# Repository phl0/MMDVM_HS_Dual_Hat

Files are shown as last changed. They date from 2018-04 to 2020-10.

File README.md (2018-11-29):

# MMDVM_HS_Dual_Hat
Duplex variant of MMDVM_HS_Hat
DB9MAT DF2ET DO7EN

This PCB uses the [MMDVM_HS](https://github.com/juribeparada/MMDVM_HS) by Andy CA6JAU. It has two ADF7021 onboard and allows for duplex operation with two time slots on DMR.

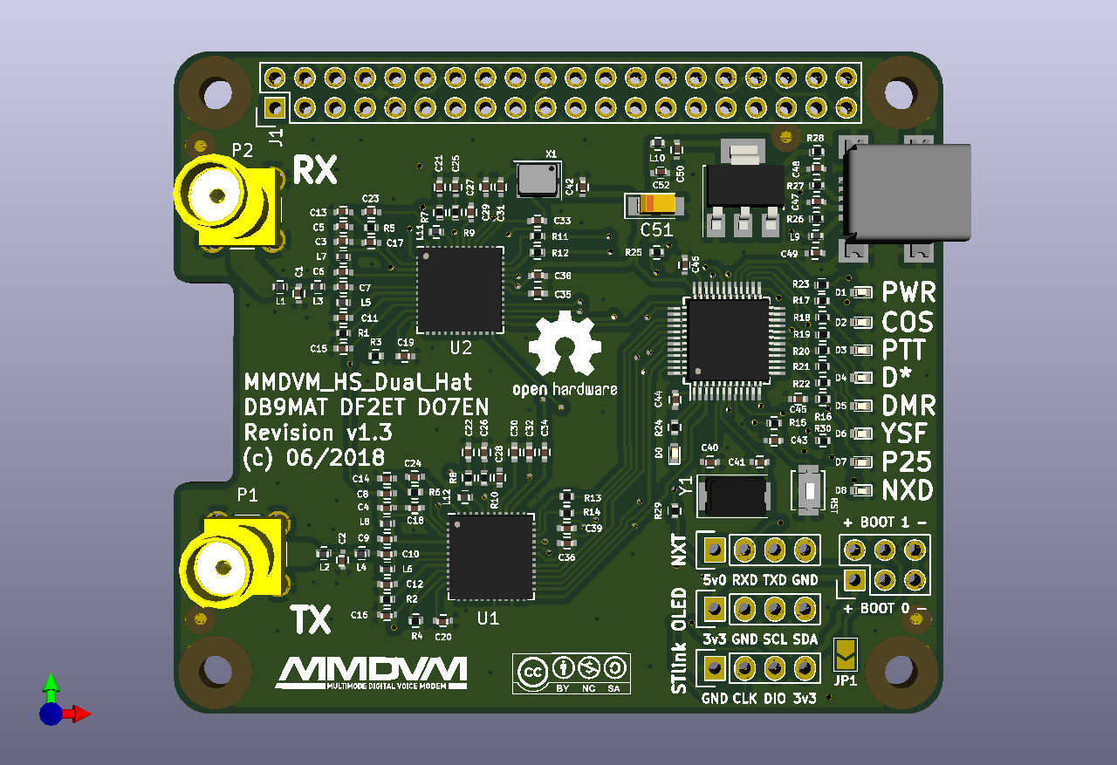
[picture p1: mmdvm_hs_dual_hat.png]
MMDVM_HS_Dual_Hat


## Revisions

### Revision 1.0

Initial release.

### Revision 1.1

LEDs D4 and D5 interchanged to align with scan order. Solder jumper JP1 was added. It can be closed if the board is used on Raspberry Pi only. It ties BOOT1 to GND. BOOT0 is controlled via GPIO. The 2x3 pin header can be unpopulated in this case to save space. We placed two coils on U1 and U2 for experiments with extended VCO. These are L11 and L12 and they are optional and do not need to be inserted for UHF use. Testpoints TP1 and TP2 on backside allows the demodulator output SNR to be measured with #define TEST_DAC compiled firmware.

**This version is not recommended for (re-)production!**

### Revision 1.2

An accidentially deleted 3v3 wire has been added back to the PCB layout. BOM, Mouser cart and stencil stay the same as for rev1.1.

### Revision 1.3

STlink header has been refactored to have the same pinout as the [MMDVM_HS_Hat](https://github.com/mathisschmieder/MMDVM_HS_Hat) boards. OLED and STlink header have been exchanged. JP1 has been slightly moved. C44, C45 and C46 have been relocated nearer to the STM32F1 CPU. A table was added to the bottom silkscreen to show which TCXO is installed. This is important to the firmware. BOM and Mouser cart are still the same. The stencil has slightly changed. If you manually solder C44-C46 you can still use the old one.

## BOM

Mouser cart for rev1.0 is [here](https://www.mouser.com/ProjectManager/ProjectDetail.aspx?AccessID=561bb01347).

[This](https://www.mouser.com/ProjectManager/ProjectDetail.aspx?AccessID=24ea9d644e) is the Mouser cart for rev1.1. L11 and L12 are optional.

## Firmware installation

The device can be used on top on a RPi attached via the GPIO port or standalone and connected via USB. Both variants require different handling of compiling and uploading the firmware. The USB connection requires firmware with bootloader support whereas the GPIO version does not. 

For USB connection a bootloader has to be installed initally. This requires STlink connection. After that is done the MMDVM_HS firmware upgrade can be done via the USB connection. The STlink connection can be used as fallback if wrongly configured firmware was installed for example.

### Install the firmware with bootloader support for USB connection

If you want to use the device via USB port you have to install a bootloader and build the firmware with bootloader support. As the raw device cannot be used with USB you have to use a USB-serial adapter or STlink device. Using STlink this can be done as follows:

```
user@host:/opt/MMDVM_HS$ make stlink-bl 
././STM32F10X_Lib/utils/linux64/st-flash write ./STM32F10X_Lib/utils/bootloader/generic_boot20_pc13.bin 0x8000000
2018-03-02T10:01:04 INFO src/usb.c: -- exit_dfu_mode
2018-03-02T10:01:04 INFO src/common.c: Loading device parameters....
2018-03-02T10:01:04 INFO src/common.c: Device connected is: F1 Medium-density device, id 0x20036410
2018-03-02T10:01:04 INFO src/common.c: SRAM size: 0x5000 bytes (20 KiB), Flash: 0x10000 bytes (64 KiB) in pages of 1024 bytes
2018-03-02T10:01:04 INFO src/common.c: Attempting to write 7160 (0x1bf8) bytes to stm32 address: 134217728 (0x8000000)
Flash page at addr: 0x08001800 erased
2018-03-02T10:01:04 INFO src/common.c: Finished erasing 7 pages of 1024 (0x400) bytes
2018-03-02T10:01:04 INFO src/common.c: Starting Flash write for VL/F0/F3 core id
2018-03-02T10:01:04 INFO src/common.c: Successfully loaded flash loader in sram
  6/6 pages written
2018-03-02T10:01:05 INFO src/common.c: Starting verification of write complete
2018-03-02T10:01:05 INFO src/common.c: Flash written and verified! jolly good!
././STM32F10X_Lib/utils/linux64/st-flash write bin/mmdvm_f1bl.bin 0x8002000
2018-03-02T10:01:05 INFO src/common.c: Loading device parameters....
2018-03-02T10:01:05 INFO src/common.c: Device connected is: F1 Medium-density device, id 0x20036410
2018-03-02T10:01:05 INFO src/common.c: SRAM size: 0x5000 bytes (20 KiB), Flash: 0x10000 bytes (64 KiB) in pages of 1024 bytes
2018-03-02T10:01:05 INFO src/common.c: Attempting to write 55016 (0xd6e8) bytes to stm32 address: 134225920 (0x8002000)
Flash page at addr: 0x0800f400 erased
2018-03-02T10:01:07 INFO src/common.c: Finished erasing 54 pages of 1024 (0x400) bytes
2018-03-02T10:01:07 INFO src/common.c: Starting Flash write for VL/F0/F3 core id
2018-03-02T10:01:07 INFO src/common.c: Successfully loaded flash loader in sram
 53/53 pages written
2018-03-02T10:01:12 INFO src/common.c: Starting verification of write complete
2018-03-02T10:01:13 INFO src/common.c: Flash written and verified! jolly good!
```

The device should now be usable as /dev/ttyACMx. 

If you want to update the MMDVM_HS firmware itself later on via USB you can use the dfu upload method. The settings in Config.h are:

    #define MMDVM_HS_DUAL_HAT_REV10
    #define ENABLE_ADF7021
    #define DUPLEX

    #define ADF7021_14_7456

or
    #define ADF7021_12_2880

for boards with 12.288MHz TCXO.

    #define STM32_USB_HOST
    #define ENABLE_SCAN_MODE

Optionally:

    #define SEND_RSSI_DATA
    #define SERIAL_REPEATER

Compile the firmware with "make bl" and then:

```
user@host:/opt/MMDVM_HS$ sudo make dfu devser=/dev/ttyACM3
././STM32F10X_Lib/utils/linux64/upload-reset /dev/ttyACM3 750
././STM32F10X_Lib/utils/linux64/dfu-util -D bin/mmdvm_f1bl.bin -d 1eaf:0003 -a 2 -R -R
dfu-util 0.7

Copyright 2005-2008 Weston Schmidt, Harald Welte and OpenMoko Inc.
Copyright 2010-2012 Tormod Volden and Stefan Schmidt
This program is Free Software and has ABSOLUTELY NO WARRANTY
Please report bugs to dfu-util@lists.gnumonks.org

Filter on vendor = 0x1eaf product = 0x0003
Opening DFU capable USB device... ID 1eaf:0003
Run-time device DFU version 0110
Found DFU: [1eaf:0003] devnum=0, cfg=1, intf=0, alt=2, name="STM32duino bootloader v1.0  Upload to Flash 0x8002000"
Claiming USB DFU Interface...
Setting Alternate Setting #2 ...
Determining device status: state = dfuIDLE, status = 0
dfuIDLE, continuing
DFU mode device DFU version 0110
Device returned transfer size 1024
No valid DFU suffix signature
Warning: File has no DFU suffix
bytes_per_hash=1100
Copying data from PC to DFU device
Starting download: [##################################################] finished!
state(8) = dfuMANIFEST-WAIT-RESET, status(0) = No error condition is present
Done!
Resetting USB to switch back to runtime mode
```

### Compile and upload manually for GPIO connection

For specific details about the firmware installation, check [these](https://github.com/juribeparada/MMDVM_HS#build-de-firmware-and-upload-to-zumspot-rpi) instructions. The process is similar to the installation on the ZumSpot Pi. You can make use of the preconfigured scripts in MMDVM_HS. Editing Config.h by hand requires these settings:

Enable the following settings in Config.h: 

    #define MMDVM_HS_DUAL_HAT_REV10
    #define ENABLE_ADF7021
    #define DUPLEX
    #define ADF7021_14_7456
    #define STM32_USART1_HOST
    #define ENABLE_SCAN_MODE

Optionally:

    #define SEND_RSSI_DATA
    #define SERIAL_REPEATER

And for 12.288MHz TCXO equipped boards

    #define ADF7021_12_2880

instead of the 14_7456 option.

Build the firmware:

    make

Make sure the two BOOT jumpers are set as follows:

    BOOT0: completey removed
    BOOT1: set to BOOT 1 -

And finally upload the firmware to the MMDVM_HS_Dual_Hat:

    sudo make mmdvm_hs_dual_hat

### Update within Pi-Star

[PiStar](http://www.pistar.uk/) contains a binary that allow for flashing precompiled binary firmware to the MMDVM_HS_Dual_Hat. To update the firmware within PiStar execute the following commands:

    $ rpi-rw
    $ pistar-mmdvmhshatflash hs_dual_hat

If you have a board equipped with 12.288MHz TCXO you have to flash the according firmware type using:

    $ pistar-mmdvmhshatflash hs_dual_hat-12mhz

## License
This project is released under the Creative Commons Attribution-NonCommercial-ShareAlike 3.0 (CC-BY-NC-SA 3.0, https://creativecommons.org/licenses/by-nc-sa/3.0/) license. You may edit and share it as you like, as long as credit is given and the license is not changed. You can build as many boards for you and your friends as you like and you can even sell it to them to cover your costs, **however it is strictly forbidden to turn this into a commercial product! You are not allowed to build and sell these boards for profit!**

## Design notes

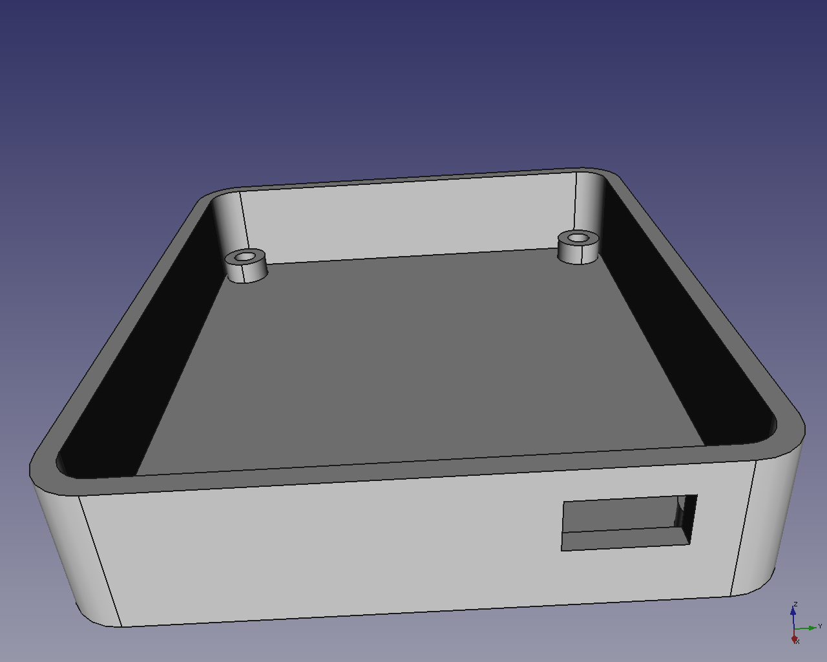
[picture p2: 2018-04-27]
case/MMDVM_HS_Dual_Hat_base.png

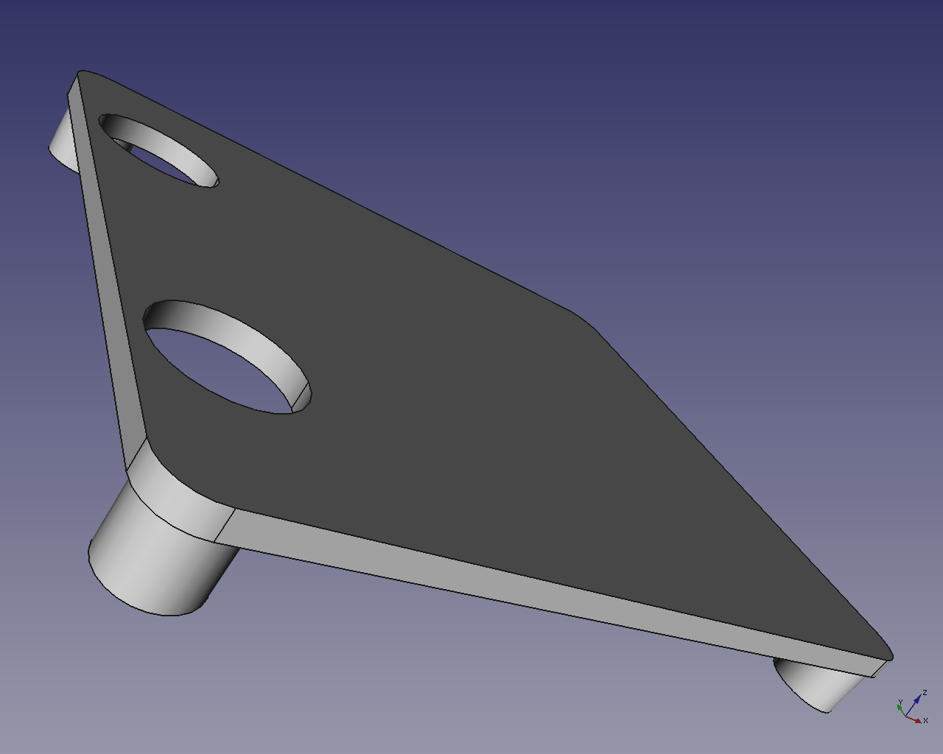
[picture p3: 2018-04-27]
case/MMDVM_HS_Dual_Hat_top.png

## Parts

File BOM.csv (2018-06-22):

Refs | Value | Footprint | Quantity | MFR | MPN | SPR | SPN
SW1 | NO | Buttons_Switches_SMD:SW_SPST_B3U-1000P | 1 | Omron Electronics | B3U-1000P | Mouser | 653-B3U-1000P
C43;C44;C45;C46;C50;C36;C20;C14;C30;C35;C19;C13;C29 | 100n | Capacitors_SMD:C_0402 | 13 | Vishay / Vitramon | VJ0402V104ZXJCW1BC | Mouser | 77-VJ0402V104ZXJCBC
C49;C39;C16;C18;C4;C32;C42;C38;C15;C17;C3;C31 | 10n | Capacitors_SMD:C_0402 | 12 | Vishay / Vitramon | VJ0402Y103KXJCW1BC | Mouser | 77-VJ0402Y103KXJCBC
C9;C6 | 10p | Capacitors_SMD:C_0402 | 2 | Murata Electronics | GRM1555C1E100GA01D | Mouser | 81-GRM1555C1E100GA1D
C52 | 10u | Capacitors_SMD:C_0402 | 1 | Murata Electronics | GRM155C80J106ME11J | Mouser | 81-GRM155C80J106ME1J
C26;C25 | 15n | Capacitors_SMD:C_0402 | 2 | Murata Electronics | GRM155R71C153KA01J | Mouser | 81-GRM155R71C153KA1J
C28;C27 | 1n | Capacitors_SMD:C_0402 | 2 | Murata Electronics | GRM155R60J102KA01D | Mouser | 81-GRM155R60J102KA1D
C40;C41 | 20p | Capacitors_SMD:C_0402 | 2 | Murata Electronics | GJM1555C1H200FB01D | Mouser | 81-GJM1555C1H200FB1D
C8;C5 | 220p | Capacitors_SMD:C_0402 | 2 | Murata Electronics | GRM1555C1H221JA01D | Mouser | 81-GRM1555C1H221JA01
C24;C23 | 22n | Capacitors_SMD:C_0402 | 2 | Murata Electronics | GCM155R71E223KA55D | Mouser | 81-GCM155R71E223KA5D
C34;C33 | 22p | Capacitors_SMD:C_0402 | 2 | AVX | 04025A220GAT2A | Mouser | 581-04025A220G
C22;C21 | 470p | Capacitors_SMD:C_0402 | 2 | Murata Electronics | GCM1555C1H471JA16J | Mouser | 81-GCM1555C1H471JA6J
C48;C47 | 47p | Capacitors_SMD:C_0402 | 2 | Murata Electronics | GRM1555C1H470FA01D | Mouser | 81-GRM1555C1H470FA1D
C10;C7 | 4p7 | Capacitors_SMD:C_0402 | 2 | Murata Electronics | GRM1555C1H4R7CA01D | Mouser | 81-GRM1555C1H4R7CA1D
C12;C2;C11;C1 | 6p8 | Capacitors_SMD:C_0402 | 4 | Murata Electronics | GJM1555C1H6R8BB01D | Mouser | 81-GJM1555C1H6R8BB1D
C51 | 10u/10V | Capacitors_Tantalum_SMD:CP_Tantalum_Case-A_EIA-3216-18_Reflow | 1 | AVX | TPSA106K010T0900 | Mouser | 581-TPSA106K010T0900
P2;P1 | SMA | Connectors:SMA_THT_Jack_Straight | 2 | TE Connectivity | 5-1814832-1 | Mouser | 571-5-1814832-1
W1;W2 | TEST_1P | Connectors_TestPoints:Test_Point_Pad_1.0x1.0mm | 2
X1 | TCXO | Crystals:Crystal_SMD_3225-4pin_3.2x2.5mm | 1 | ECS | ECS-TXO-3225-147.4-TR | Mouser | 520-TXO-3225-14.74T
Y1 | 8MHz | Crystals:Crystal_SMD_Abracon_ABM3-2pin_5.0x3.2mm | 1 | ABRACON | ABM3-8.000MHz-D2Y-T | Mouser | 815-ABM3-8-D2Y-T
U1;U2 | ADF7021 | Housings_DFN_QFN:QFN-48-1EP_7x7mm_Pitch0.5mm | 2 | Analog Devices | ADF7021BCPZ | Mouser | 584-ADF7021BCPZ
U3 | STM32F103C8T6 | Housings_QFP:LQFP-48_7x7mm_Pitch0.5mm | 1 | STMicroelectronics | STM32F103C8T6 | Mouser | 511-STM32F103C8T6
L9 | 100MHz | Inductors_SMD:L_0402 | 1 | Wurth Electronics | 74279277 | Mouser | 710-74279277
L10 | 10u | Inductors_SMD:L_0402 | 1 | Wurth Electronics | 74279277 | Mouser | 710-74279277
L8;L7 | 13n | Inductors_SMD:L_0402 | 2 | Murata Electronics | LQW15AN13NG80D | Mouser | 81-LQW15AN13NG80D
L12;L11 | 18n | Inductors_SMD:L_0402 | 2 | TE Connectivity / Sigma Inductors | 36501E18NJTDG | Mouser | 279-36501E18NJTDG
L4;L3 | 20n | Inductors_SMD:L_0402 | 2 | TE Connectivity / Sigma Inductors | 36501E20NJTDG | Mouser | 279-36501E20NJTDG
L2;L1 | 22n | Inductors_SMD:L_0402 | 2 | Murata Electronics | LQW15CA22NJ00D | Mouser | 81-LQW15CA22NJ00D
L6;L5 | 27n | Inductors_SMD:L_0402 | 2 | Murata Electronics | LQW15AN27NG80D | Mouser | 81-LQW15AN27NG80D
JP1 | SolderJumper_2_Open | Jumper:SolderJumper-2_P1.3mm_Open_TrianglePad1.0x1.5mm | 1
D6 | amber | LEDs:LED_0402 | 1 | Kingbright | APHHS1005SECK | Mouser | 604-APHHS1005SECK
D8 | blue | LEDs:LED_0402 | 1 | Kingbright | APHHS1005QBC/D | Mouser | 604-APHHS1005QBCD
D1;D4 | green | LEDs:LED_0402 | 2 | Kingbright | APHHS1005CGCK | Mouser | 604-APHHS1005CGCK
D3;D7;D0 | red | LEDs:LED_0402 | 3 | Kingbright | APHHS1005SURCK | Mouser | 604-APHHS1005SURCK
D2;D5 | yellow | LEDs:LED_0402 | 2 | Kingbright | APHHS1005SYCK | Mouser | 604-APHHS1005SYCK
P8 | USB_OTG | MMDVM:USB-mini-710-65100516121 | 1 | Wurth Electronics | 65100516121 | Mouser | 710-65100516121
P4 | DISPLAY | Pin_Headers:Pin_Header_Straight_1x04 | 1 | TE Connectivity / AMP | 826629-4 | Mouser | 571-826629-4
P3 | I2C | Pin_Headers:Pin_Header_Straight_1x04 | 1 | TE Connectivity / AMP | 826629-4 | Mouser | 571-826629-4
P5 | STLINK | Pin_Headers:Pin_Header_Straight_1x04 | 1 | TE Connectivity / AMP | 826629-4 | Mouser | 571-826629-4
P7 | CONN_02X03 | Pin_Headers:Pin_Header_Straight_2x03 | 1 | TE Connectivity / AMP | 826632-3 | Mouser | 571-826632-3
J1 | RPi_GPIO | Pin_Headers:Pin_Header_Straight_2x20 | 1 | Harwin | M20-7832046 | Mouser | 855-M20-7832046
R30;R29 | 100k | Resistors_SMD:R_0402 | 2 | Vishay | CRCW0402100KFKED | Mouser | 71-CRCW0402-100K-E3
R15;R25 | 10k | Resistors_SMD:R_0402 | 2 | Vishay | CRCW040210K0JNEDC | Mouser | 71-CRCW040210K0JNEDC
R16;R17;R18;R19;R20;R21;R22;R24;R23;R13;R14;R11;R12 | 1k | Resistors_SMD:R_0402 | 13 | Vishay | RCS04021K00JNED | Mouser | 71-RCS04021K00JNED
R2;R1 | 1k1 | Resistors_SMD:R_0402 | 2 | Susumu | RR0510P-112-D | Mouser | 754-RR0510P-112D
R28 | 1k5 | Resistors_SMD:R_0402 | 1 | Panasonic | ERA-2AED152X | Mouser | 667-ERA-2AED152X
R10;R9 | 270 | Resistors_SMD:R_0402 | 2 | Panasonic | ERA-2AEB271X | Mouser | 667-ERA-2AEB271X
R27;R26 | 27R | Resistors_SMD:R_0402 | 2 | Susumu | RR0510R-270-D | Mouser | 754-RR0510R-270D
R4;R3 | 3k8 | Resistors_SMD:R_0402 | 2 | Susumu | RR0510P-3831-D | Mouser | 754-RR0510P-3831D
R6;R5 | 3r9 | Resistors_SMD:R_0402 | 2 | Vishay | CRCW04023R90JNED | Mouser | 71-CRCW0402J-3.9-E3
R8;R7 | 560 | Resistors_SMD:R_0402 | 2 | Panasonic | ERA-2AEB561X | Mouser | 667-ERA-2AEB561X
U4 | LD1117S33TR | TO_SOT_Packages_SMD:SOT-223-3_TabPin2 | 1 | Microchip Technology | TC2117-3.3VDBTR | Mouser | 579-TC2117-3.3VDBTR

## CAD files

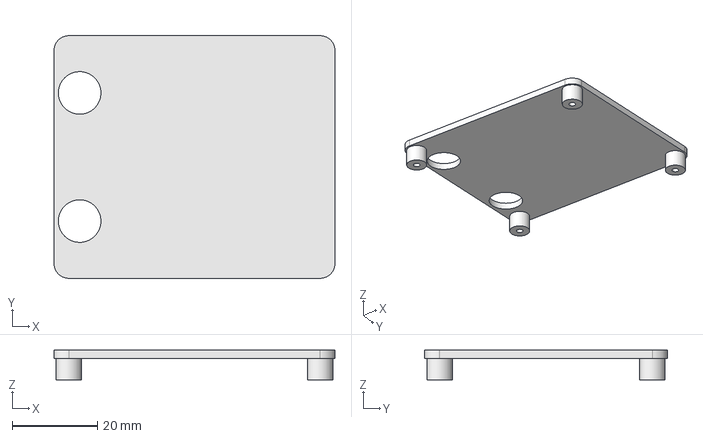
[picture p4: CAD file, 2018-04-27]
case/MMDVM_HS_Dual_Hat_top.fcstd
66.0 x 57.0 x 7.00 mm

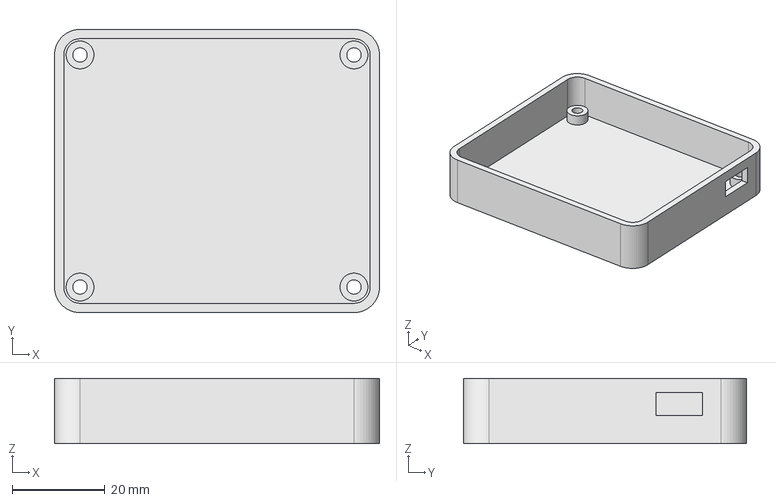
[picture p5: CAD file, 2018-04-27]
case/MMDVM_HS_Dual_Hat_base.fcstd
70.0 x 61.0 x 14.0 mm

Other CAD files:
case/MMDVM_HS_Dual_Hat_base.stl
case/MMDVM_HS_Dual_Hat_top.stl

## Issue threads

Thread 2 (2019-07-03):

TCXO COMOS connected to OSC2

sp2ong, 2019-07-03:
Hi
I have read article RA3APW and he suggests that TCXO CMOS version (in most cases we use) the TCXO should be connected to OSC2 pin put instead OSC1 on ADF7021:

https://www.analog.com/media/en/technical-documentation/data-sheets/ADF7021.pdf

See page 48:

"Set XOSC_ENABLE high when using an external crystal. If using an external oscillator (such as TCXO) with CMOS-level outputs into Pin OSC2, set XOSC_ENABLE low. If using an external oscillator with a 0.8 V p-p clipped sine wave output into Pin OSC1, set XOSC_ENABLE high. "

Source information:
http://www.ra3apw.ru/mmdvm-%D0%B8-tcxo/

phl0, 2019-07-03:
Tnx for information. We will consider that once we make a new revision of the board.

dgiese, 2020-05-02:
Out of curiosity: What effects does the OSC1 instead of OSC2 pin connection have?

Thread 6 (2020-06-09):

The STM32F103C8T6's rom size is not enough for USB

jcyfkimi, 2020-06-09:
Hi
   I just build your board and found that the STM32F103C8T6's ROM size is not enough for USB version, only can go for GPIO. Replacing the MCU with STM32F103CBT6 can make it work. It has 128K ROM.

ra1nb0w, 2021-03-22:
Have you tried the STM32F103CBT6?

jcyfkimi, 2021-03-23:
> Have you tried the STM32F103CBT6?

Yes, I'm using STM32F103CBT6 right now. Works both for GPIO and USB.

ra1nb0w, 2021-03-23:
Ok. Thank you @jcyfkimi

ra1nb0w, 2021-03-23:
Now, the hard point is to find it from a distributor :)

jcyfkimi, 2021-03-31:
Yeah, that's really a disaster. Not sure what's your location, I checked with mouser usa, it's still available, just for the price. Or you can try with aliexpress.

ra1nb0w, 2021-03-31:
In my mouser (EU) it is not available (511-STM32F103CBT6); on order without ETA.

jcyfkimi, 2021-03-31:
Maybe have a try with aliexpress, I know lots of the chips come from aliexpress are recycled and the quailty varies, even with fake chips (for stm32 microcontrollers, I don't think there're fake chips), but considering current stocking status as well as the price issue, I think it's worth to try.

ra1nb0w, 2021-03-31:
Yes, I will try. Thank you.

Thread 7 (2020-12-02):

Not able to open 2.0-mini schematic because there is a .sch file missing.

pufferfish42, 2020-12-02:
Hello,
I am trying to build the 2.0-mini schematic. However the *.sch files are missing, so it is not possible to open the project. Could you please submit the *.sch files?
Thanks in advance!

phl0, 2020-12-02:
There is a .kicad_sch file. You may need a more recent version of KiCad ;-)

pufferfish42, 2020-12-03:
I am using latest stable version of Kicad (5.1.8) in Fedora. Are you using nightly builds of Kicad?

Closed 2020-12-02.

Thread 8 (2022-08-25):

Raspberry Pi CM4 Carrier Board plans?

ceilingduster, 2022-08-25:
Any plans to add the Hirose connectors to a RPi CM4 instead of the GPIO?  An all in one board with a 18560 battery would be nice!!

ceilingduster, 2022-08-25:
https://github.com/dronecz/Minimal_carrier_board_for_CM4

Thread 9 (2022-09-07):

Kicad files for DUAL HAT

PD5DJ, 2022-09-07:
Where can we find the Kicad files for the Dual hat?
Specially Step files for the PCB

I like to make a custom Enclosure for the Dual HAT.

phl0, 2022-09-08:
See the [hardware folder](https://github.com/phl0/MMDVM_HS_Dual_Hat/tree/master/hardware) in this repo.

Closed 2022-09-08.

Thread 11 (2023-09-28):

Not working in duplex GPIO

jjsainzc, 2023-09-28:
How can I use as dupkex with pi-star ? I selected MMDVM_HS_Dual_Hat (DB9MAT, DF2ET, & DO7EN) for Pi (GPIO) and not work, only when I use  MMDVM_HS-MDO Hat (BG3MDO) for Pi (GPIO) in simplex mode works, thanks so much, please help me

phl0, 2023-09-29:
> How can I use as dupkex with pi-star ? I selected MMDVM_HS_Dual_Hat (DB9MAT, DF2ET, & DO7EN) for Pi (GPIO) and not work, only when I use MMDVM_HS-MDO Hat (BG3MDO) for Pi (GPIO) in simplex mode works, thanks so much, please help me

Which version of the HAT do you have and which version of firmware pls?

jjsainzc, 2023-09-29:
Sorry my ignorance, how can i get the firmware version of mmdvm hat ?

Best regards
73's HC1LNM
https://www.qrz.com/db/HC1LNM
+593 98 443 0010

Jorge Jesus Sainz Casalla
Freelance senior software developement and consultant.

El jue, 28 sept 2023 a la(s) 23:59, Florian (DF2ET) (
***@***.***) escribió:

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

phl0, 2023-09-29:
> Sorry my ignorance, how can i get the firmware version of mmdvm hat ? Best regards 73's

It is read upon start of MMDVMHost and written to the logs. What hardware board are you using?

jjsainzc, 2023-09-29:
Hey again

Im using Raspberry Pi 3 Model B Plus Rev 1.3

My radio info show HS_HAT: V1.5.2

Best regards
73's HC1LNM
https://www.qrz.com/db/HC1LNM
+593 98 443 0010

Jorge Jesus Sainz Casalla
Freelance senior software developement and consultant.

El vie, 29 sept 2023 a la(s) 06:08, Florian (DF2ET) (
***@***.***) escribió:

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

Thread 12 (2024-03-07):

usb support

PripyatAutomations, 2024-03-07:
has anyone actually used this hat with the usb connection? having some issues building the firmware, looks like im missing usb serial library.

PripyatAutomations, 2024-03-07:
arm-none-eabi-g++ obj_f1/ADF7021.o obj_f1/BitRB.o obj_f1/CalDMR.o obj_f1/CalRSSI.o obj_f1/CWIdTX.o obj_f1/DMRDMORX.o obj_f1/DMRDMOTX.o obj_f1/DMRIdleRX.o obj_f1/DMRRX.o obj_f1/DMRSlotRX.o obj_f1/DMRSlotType.o obj_f1/DMRTX.o obj_f1/DStarRX.o obj_f1/DStarTX.o obj_f1/I2CHost.o obj_f1/IOArduino.o obj_f1/IO.o obj_f1/IOSTM.o obj_f1/M17RX.o obj_f1/M17TX.o obj_f1/MMDVM_HS.o obj_f1/NXDNRX.o obj_f1/NXDNTX.o obj_f1/P25RX.o obj_f1/P25TX.o obj_f1/POCSAGTX.o obj_f1/SerialArduino.o obj_f1/SerialPort.o obj_f1/SerialRB.o obj_f1/SerialSTM.o obj_f1/Utils.o obj_f1/YSFRX.o obj_f1/YSFTX.o obj_f1/misc.o obj_f1/stm32f10x_exti.o obj_f1/stm32f10x_gpio.o obj_f1/stm32f10x_i2c.o obj_f1/stm32f10x_iwdg.o obj_f1/stm32f10x_rcc.o obj_f1/stm32f10x_usart.o obj_f1/system_stm32f10x.o obj_f1/startup_stm32f10x.o  -Os --specs=nano.specs --specs=nosys.specs -T normal.ld -mcpu=cortex-m3 -march=armv7-m -mthumb -Wall -Wextra  -o bin/mmdvm_f1.elf
/usr/lib/gcc/arm-none-eabi/13.2.1/../../../arm-none-eabi/bin/ld: obj_f1/SerialSTM.o: in function `CSerialPort::beginInt(unsigned char, int)':
SerialSTM.cpp:(.text._ZN11CSerialPort8beginIntEhi+0x5c): undefined reference to `usbserial'
/usr/lib/gcc/arm-none-eabi/13.2.1/../../../arm-none-eabi/bin/ld: SerialSTM.cpp:(.text._ZN11CSerialPort8beginIntEhi+0x3a): undefined reference to `USBSerial::begin()'
/usr/lib/gcc/arm-none-eabi/13.2.1/../../../arm-none-eabi/bin/ld: obj_f1/SerialSTM.o: in function `CSerialPort::availableInt(unsigned char)':
SerialSTM.cpp:(.text._ZN11CSerialPort12availableIntEh+0x20): undefined reference to `usbserial'
/usr/lib/gcc/arm-none-eabi/13.2.1/../../../arm-none-eabi/bin/ld: SerialSTM.cpp:(.text._ZN11CSerialPort12availableIntEh+0x14): undefined reference to `USBSerial::available()'
/usr/lib/gcc/arm-none-eabi/13.2.1/../../../arm-none-eabi/bin/ld: obj_f1/SerialSTM.o: in function `CSerialPort::readInt(unsigned char)':
SerialSTM.cpp:(.text._ZN11CSerialPort7readIntEh+0x10): undefined reference to `USBSerial::read()'
/usr/lib/gcc/arm-none-eabi/13.2.1/../../../arm-none-eabi/bin/ld: SerialSTM.cpp:(.text._ZN11CSerialPort7readIntEh+0x20): undefined reference to `usbserial'
/usr/lib/gcc/arm-none-eabi/13.2.1/../../../arm-none-eabi/bin/ld: obj_f1/SerialSTM.o: in function `CSerialPort::writeInt(unsigned char, unsigned char const*, unsigned short, bool)':
SerialSTM.cpp:(.text._ZN11CSerialPort8writeIntEhPKhtb+0x18): undefined reference to `USBSerial::write(unsigned char const*, unsigned long)'
/usr/lib/gcc/arm-none-eabi/13.2.1/../../../arm-none-eabi/bin/ld: SerialSTM.cpp:(.text._ZN11CSerialPort8writeIntEhPKhtb+0x3c): undefined reference to `usbserial'
/usr/lib/gcc/arm-none-eabi/13.2.1/../../../arm-none-eabi/bin/ld: SerialSTM.cpp:(.text._ZN11CSerialPort8writeIntEhPKhtb+0x26): undefined reference to `USBSerial::flush()'
collect2: error: ld returned 1 exit status

PripyatAutomations, 2024-03-07:
diff --git a/Makefile b/Makefile
index c73834e..626ef19 100644
--- a/Makefile
+++ b/Makefile
@@ -179,7 +179,7 @@ STARTUP_F4=$(wildcard $(STARTUP_DIR_F4)/*.c)
 CSRC_STD_F7=$(wildcard $(STD_LIB_F7)/*.c)
 SYS_F7=$(wildcard $(SYS_DIR_F7)/*.c)
 STARTUP_F7=$(wildcard $(STARTUP_DIR_F7)/*.c)
-OBJ_F1=$(CXXSRC:$(MMDVM_HS_PATH)/%.cpp=$(OBJDIR_F1)/%.o) $(CSRC_STD_F1:$(STD_LIB_F1)/%.c=$(OBJDIR_F1)/%.o) $(SYS_F1:$(SYS_DIR_F1)/%.c=$(OBJDIR_F1)/%.o) $(STARTUP_F1:$(STARTUP_DIR_F1)/%.c=$(OBJDIR_F1)/%.o)
+OBJ_F1=$(CXXSRC:$(MMDVM_HS_PATH)/%.cpp=$(OBJDIR_F1)/%.o) $(CSRC_STD_F1:$(STD_LIB_F1)/%.c=$(OBJDIR_F1)/%.o) $(SYS_F1:$(SYS_DIR_F1)/%.c=$(OBJDIR_F1)/%.o) $(STARTUP_F1:$(STARTUP_DIR_F1)/%.c=$(OBJDIR_F1)/%.o) $(CXX_USB_F1:$(USB_F1)/%.cpp=$(OBJDIR_F1)/%.o) $(C_USB_F1:$(USB_F1)/%.c=$(OBJDIR_F1)/%.o)
 OBJ_F1BL=$(CXXSRC:$(MMDVM_HS_PATH)/%.cpp=$(OBJDIR_F1)/%.o) $(CSRC_STD_F1:$(STD_LIB_F1)/%.c=$(OBJDIR_F1)/%.o) $(SYS_F1:$(SYS_DIR_F1)/%.c=$(OBJDIR_F1)/%.o) $(STARTUP_F1:$(STARTUP_DIR_F1)/%.c=$(OBJDIR_F1)/%.o) $(CXX_USB_F1:$(USB_F1)/%.cpp=$(OBJDIR_F1)/%.o) $(C_USB_F1:$(USB_F1)/%.c=$(OBJDIR_F1)/%.o)
 OBJ_F4=$(CXXSRC:$(MMDVM_HS_PATH)/%.cpp=$(OBJDIR_F4)/%.o) $(CSRC_STD_F4:$(STD_LIB_F4)/%.c=$(OBJDIR_F4)/%.o) $(SYS_F4:$(SYS_DIR_F4)/%.c=$(OBJDIR_F4)/%.o) $(STARTUP_F4:$(STARTUP_DIR_F4)/%.c=$(OBJDIR_F4)/%.o)
 OBJ_F7=$(CXXSRC:$(MMDVM_HS_PATH)/%.cpp=$(OBJDIR_F7)/%.o) $(CSRC_STD_F7:$(STD_LIB_F7)/%.c=$(OBJDIR_F7)/%.o) $(SYS_F7:$(SYS_DIR_F7)/%.c=$(OBJDIR_F7)/%.o) $(STARTUP_F7:$(STARTUP_DIR_F7)/%.c=$(OBJDIR_F7)/%.o)

Closed 2024-03-07.

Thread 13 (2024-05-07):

Enable boot mode on an STM32 aliexpress clone

sysadminpower2019, 2024-05-07:
Hello,

I have been trying to update my firmware for this board but have no had any luck. Apparently it needs to be put into bootloader mode but there does not seem to be any obvious place on the board to work with.

Here is a link to the board. Hopefully at least someone can point me in the right direction to try things out.

https://www.aliexpress.com/item/1005006281394445.html
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

the chip seems to be a geehy apm32 f103cbt6

thanks very much

phl0, 2024-05-07:
This board is not supported by this repo. Please contact the seller. Sorry.

sysadminpower2019, 2024-05-07:
I contacted the seller they said their distributor has no idea either. Any idea where I could turn to support for this board?

phl0, 2024-05-07:
> I contacted the seller they said their distributor has no idea either. Any idea where I could turn to support for this board?

Nope sri.

Closed 2024-05-07.

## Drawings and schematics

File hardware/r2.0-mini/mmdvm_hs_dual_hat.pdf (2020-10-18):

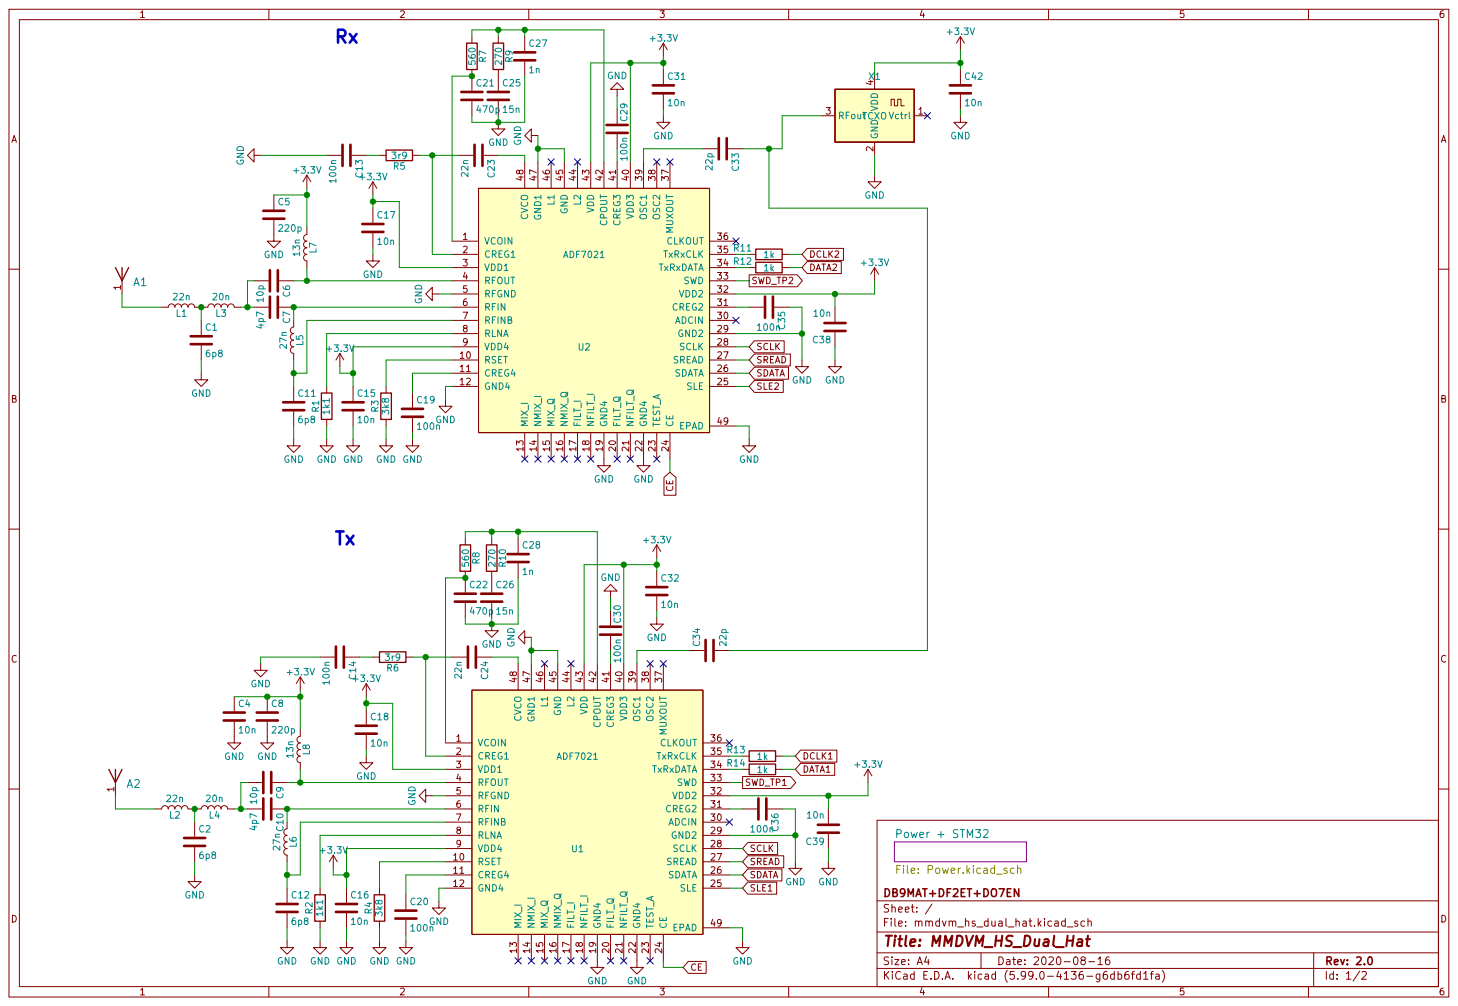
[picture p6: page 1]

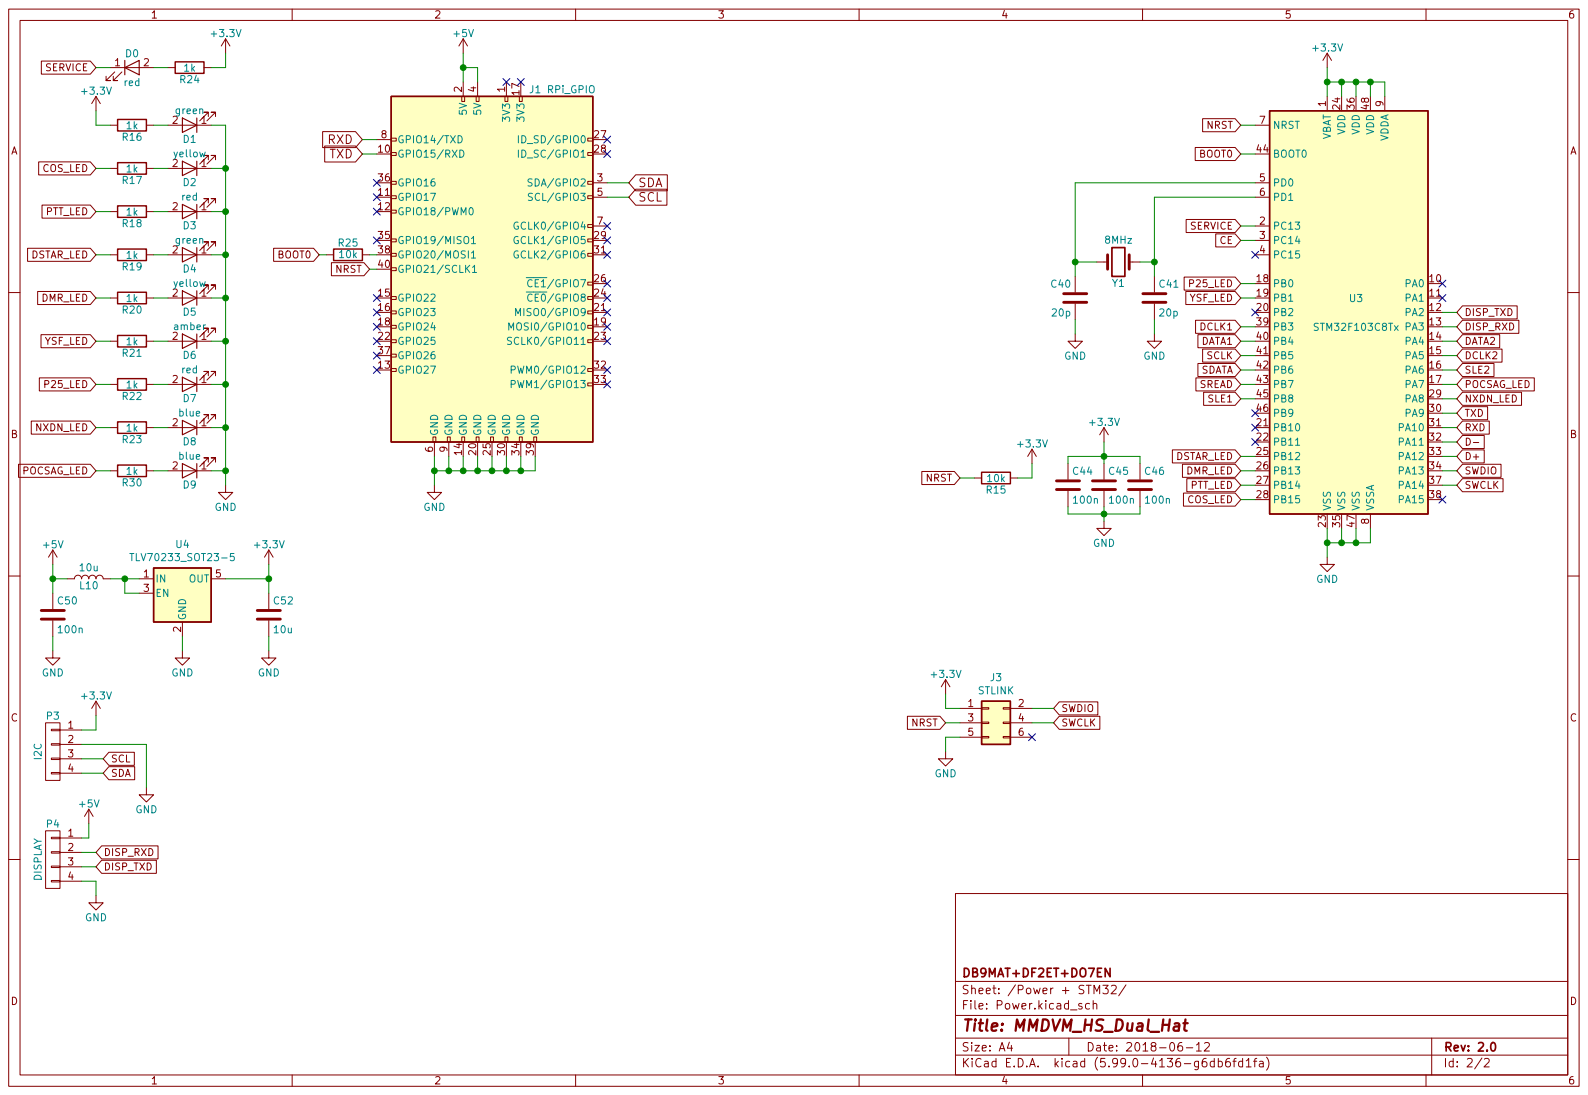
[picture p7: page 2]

File: Power.kicad_sch Sheet: /Power + STM32/ DB9MAT+DF2ET+DO7EN

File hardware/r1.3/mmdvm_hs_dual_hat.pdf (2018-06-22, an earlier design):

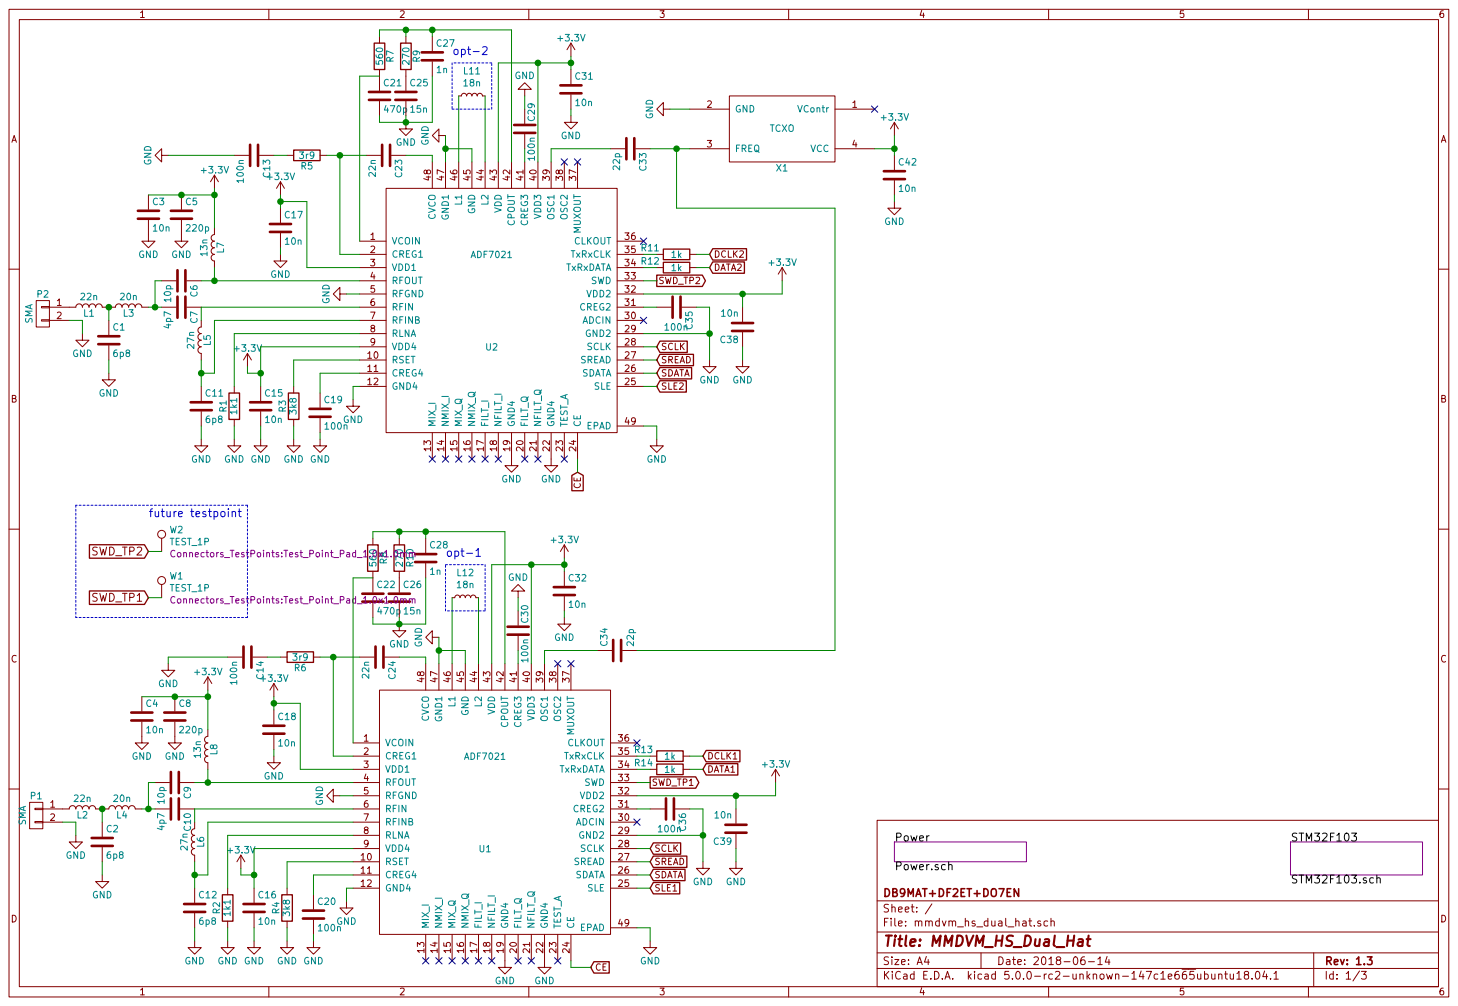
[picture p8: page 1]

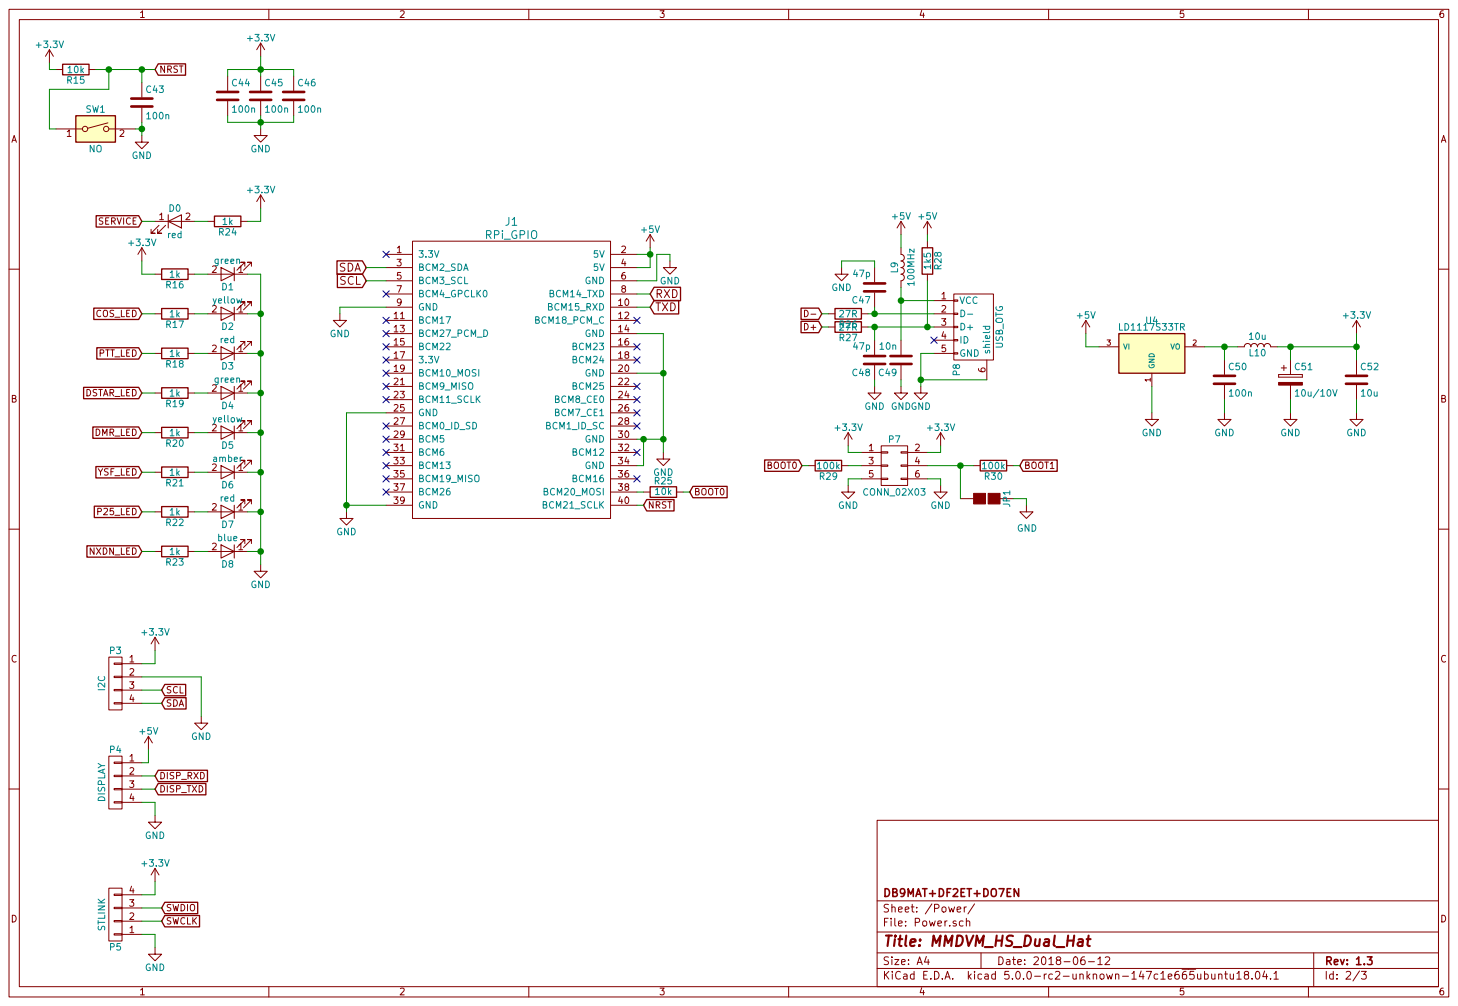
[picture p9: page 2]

Id: 2/3 Title: MMDVM_HS_Dual_Hat File: Power.sch Sheet: /Power/ DB9MAT+DF2ET+DO7EN

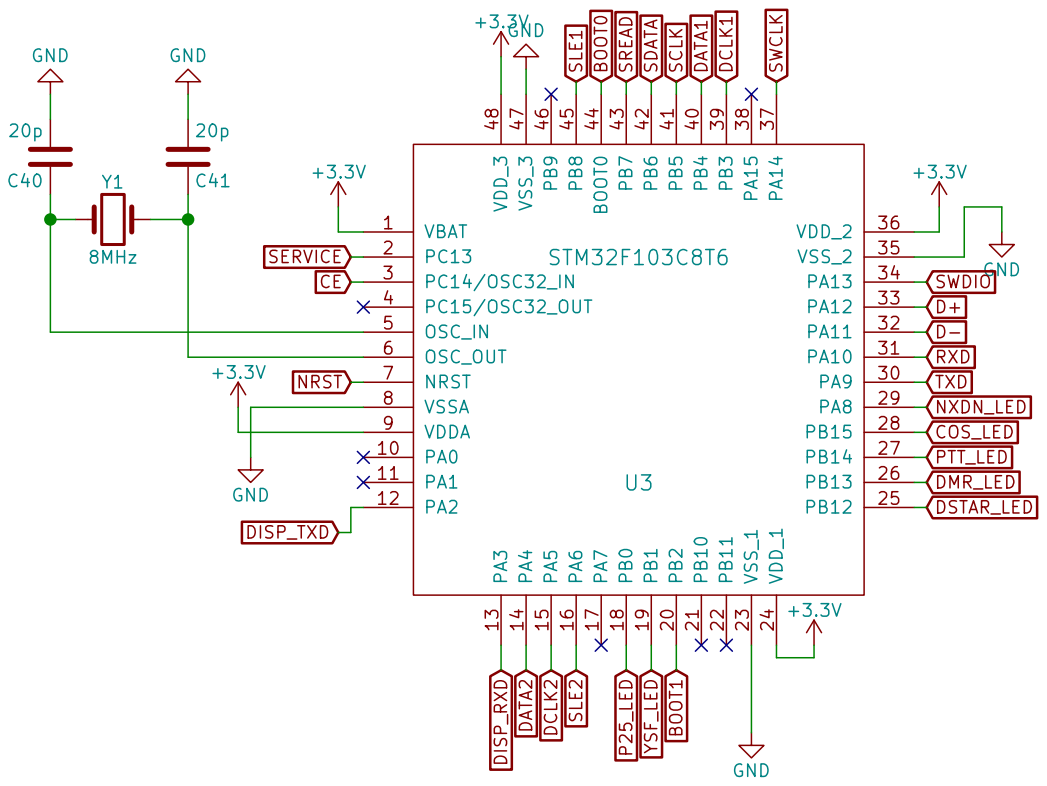
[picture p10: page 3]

Id: 3/3 Title: MMDVM_HS_Dual_Hat File: STM32F103.sch Sheet: /STM32F103/ DB9MAT+DF2ET+DO7EN

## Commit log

2018-01-23 Initial commit of schematic
    [mmdvm_hs_dual_hat.kicad_pcb, mmdvm_hs_dual_hat.sch]
2018-01-24 Realign misplaced RPi connector
    [mmdvm_hs_dual_hat.kicad_pcb]
2018-01-24 Sort components
    [mmdvm_hs_dual_hat.kicad_pcb]
2018-01-24 Add zones
    [mmdvm_hs_dual_hat.kicad_pcb]
2018-01-24 Align components roughly
    [mmdvm_hs_dual_hat.kicad_pcb]
2018-01-24 Add USB connector and change to +5V source
    [mmdvm_hs_dual_hat.kicad_pcb, mmdvm_hs_dual_hat.sch]
2018-01-24 First routings
    [mmdvm_hs_dual_hat.kicad_pcb, mmdvm_hs_dual_hat.sch]
2018-01-24 Add NXDN LED
    [mmdvm_hs_dual_hat.kicad_pcb, mmdvm_hs_dual_hat.sch]
2018-01-24 Some more routing added
    [mmdvm_hs_dual_hat.kicad_pcb, mmdvm_hs_dual_hat.sch]
2018-01-29 Some more routing and beautification
    [mmdvm_hs_dual_hat.kicad_pcb]
2018-02-01 More routing .,..
    [mmdvm_hs_dual_hat.kicad_pcb]
2018-02-04 Integrate work by DO7EN
    [mmdvm_hs_dual_hat.kicad_pcb, mmdvm_hs_dual_hat.sch]
2018-02-04 added missed files
    [Power.sch, STM32F103.sch, mmdvm_hs_dual_hat.kicad_pcb]
2018-02-04 Align filled zones outline
    [mmdvm_hs_dual_hat.kicad_pcb, mmdvm_hs_dual_hat.sch]
2018-02-04 Exchange PWR and NXD LEDs
    [mmdvm_hs_dual_hat.kicad_pcb]
2018-02-04 GND VIAs for everyone
    [mmdvm_hs_dual_hat.kicad_pcb]
2018-02-05 resize ans scaling 3D objects
    [Power.sch, STM32F103.sch, mmdvm_hs_dual_hat.kicad_pcb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]
2018-02-05 Moved USB connector slightly inwards
    [mmdvm_hs_dual_hat.kicad_pcb]
2018-02-05 Rotated OLED header by 180°
    [mmdvm_hs_dual_hat.kicad_pcb]
2018-02-05 Align text prints
    [mmdvm_hs_dual_hat.kicad_pcb]
2018-02-05 Add some nice logos
    [mmdvm_hs_dual_hat.kicad_pcb]
2018-02-05 Update meta info
    [mmdvm_hs_dual_hat.sch]
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2018-02-05 Correct USB footprint, add C53 to select TCXO
    [Power.sch, mmdvm_hs_dual_hat.sch]
2018-02-06 Add BOM
    [BOM.csv, BOM.xlsx, Power.sch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]
2018-02-06 add USB-mini-Mouser Footprint
    [Power.sch, STM32F103.sch, mmdvm_hs_dual_hat.sch]
2018-02-07 correction of value P1 and P2. routing USB to GND
    [mmdvm_hs_dual_hat.sch]
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2018-02-10 STLink connector user-friendly orientation
    [Power.sch]
2018-02-14 new final PCB release
    [mmdvm_hs_dual_hat.kicad_pcb, mmdvm_hs_dual_hat.sch]
2018-02-14 Add 100k resistors R29 and R30
    [BOM.csv, BOM.xlsx, Power.sch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]
2018-02-14 Make references for LEDs visible
    [mmdvm_hs_dual_hat.kicad_pcb]
2018-02-14 Correct strange CE wire ...
    [mmdvm_hs_dual_hat.kicad_pcb]
2018-02-14 Make HF wires to P1 a little wider
    [mmdvm_hs_dual_hat.kicad_pcb]
2018-02-14 Add + and - to BOOT0/1 reference
    [mmdvm_hs_dual_hat.kicad_pcb]
2018-02-14 Add MMDVM Logo to front
    [mmdvm_hs_dual_hat.kicad_pcb]
2018-02-14 Logos all over the place :)
    [mmdvm_hs_dual_hat.kicad_pcb]
2018-02-14 Correct GND zone fill
2018-02-14 Add VIAs to ADF7021s
    [mmdvm_hs_dual_hat.kicad_pcb]
2018-02-14 Correct GND VIAs and make 3v3 wires wider
    [mmdvm_hs_dual_hat.kicad_pcb]
2018-02-14 Add more VIAs
    [mmdvm_hs_dual_hat.kicad_pcb]
2018-02-14 impedance 1.4mm 52.13 Ohm 1.6mm 50.2 Ohm
    [mmdvm_hs_dual_hat.kicad_pcb]
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2018-02-15 P1 bridge removed
    [mmdvm_hs_dual_hat.kicad_pcb]
2018-02-15 Beautify VIAs around silkscreen
    [mmdvm_hs_dual_hat.kicad_pcb]
2018-02-15 Add and update BOM for rev0.1
    [BOM.csv, BOM.xlsx, Power.sch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]
2018-02-28 Add RX/TX labels to SMA sockets
    [mmdvm_hs_dual_hat.kicad_pcb]
2018-02-28 Remove 2nd TCXO as it is not needed
    [BOM.csv, BOM.xlsx, Power.sch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]
2018-02-28 Final adjustments to 3D models and release rev1.0
    [mmdvm_hs_dual_hat.kicad_pcb]
2018-02-28 Move RX/TX labels
    [mmdvm_hs_dual_hat.kicad_pcb]
2018-03-02 Add solder jumper for BOOT1
    [Power.sch, mmdvm_hs_dual_hat.kicad_pcb]
2018-03-02 Interchange D4 and D5
    [BOM.csv, BOM.xlsx, Power.sch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]
2018-03-02 add inductors for extended VCO
    [Power.sch, mmdvm_hs_dual_hat.kicad_pcb, mmdvm_hs_dual_hat.sch]
2018-03-02 Add labels and hint for L11 and L12
    [mmdvm_hs_dual_hat.kicad_pcb]
2018-03-02 Add 3D shapes for L11 and L12
    [mmdvm_hs_dual_hat.kicad_pcb]
2018-03-02 Correct L11 and L12 value and add them to BOM
    [BOM.csv, BOM.xlsx, Power.sch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]
2018-03-02 Exchange RX/TX pins on NXT header. Update L11/12 footprints
    [Power.sch, STM32F103.sch, mmdvm_hs_dual_hat.kicad_pcb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]
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2018-03-04 Correct TP1 and add TP2
    [Power.sch, mmdvm_hs_dual_hat.kicad_pcb, mmdvm_hs_dual_hat.sch]
2018-03-05 Fix 3v3 line
    [mmdvm_hs_dual_hat.kicad_pcb]
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2018-03-05 Fix GND wire near via and resize JP1 track
    [mmdvm_hs_dual_hat.kicad_pcb]
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2018-03-05 Add more GND and vias
    [mmdvm_hs_dual_hat.kicad_pcb]
2018-03-05 add via near LDO
    [mmdvm_hs_dual_hat.kicad_pcb]
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2018-03-13 Restore deleted 3v3 wire
    [mmdvm_hs_dual_hat.kicad_pcb, mmdvm_hs_dual_hat.sch]
2018-03-14 Added a few more vias
    [mmdvm_hs_dual_hat.kicad_pcb]
2018-03-14 Add note to rev1.1
    [mmdvm_hs_dual_hat.kicad_pcb]
2018-03-23 Component values, position and size changed F.Fab
    [mmdvm_hs_dual_hat.kicad_pcb]
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2018-04-03 Replace 470pF capacitors
    [BOM.csv, BOM.xlsx, Power.sch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]
2018-04-27 Add sources for 3D printed case for USB only Hat
    [MMDVM_HS_Dual_Hat_base.fcstd, MMDVM_HS_Dual_Hat_base.stl, MMDVM_HS_Dual_Hat_top.fcstd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]
2018-06-12 Refactor STlink connector to match w/ MMDVM_HS_Hat
    [Power.sch, STM32F103.sch, mmdvm_hs_dual_hat.kicad_pcb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]
2018-06-12 Exchange OLED and STlink headers
    [mmdvm_hs_dual_hat.kicad_pcb]
2018-06-12 Update 3d shapes for LEDs
    [mmdvm_hs_dual_hat.kicad_pcb]
2018-06-12 Add info table for used TCXO frequency
    [mmdvm_hs_dual_hat.kicad_pcb]
2018-06-14 Revert "Add info table for used TCXO frequency"
    This reverts commit 995517471a6a9c3a2a24c54cffd6013342e8fae5.
    [mmdvm_hs_dual_hat.kicad_pcb]
2018-06-14 Revert "Update 3d shapes for LEDs"
    This reverts commit 114b8558ea413cd9a3e428f81de237fed2d875d2.
    [mmdvm_hs_dual_hat.kicad_pcb]
2018-06-14 Moved C44-46 to STM32
    [mmdvm_hs_dual_hat.kicad_pcb]
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2018-06-14 Remove 3d shapes for pin headers
    [mmdvm_hs_dual_hat.kicad_pcb]
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2018-06-21 Fix upper left fiducial
    [mmdvm_hs_dual_hat.kicad_pcb]
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2020-08-16 Cleaned up libraries and schematics
    Preparation for Revision 2.0
    [Power.sch, STM32F103.sch, mmdvm_hs_dual_hat.kicad_pcb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]
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2020-10-18 Added revision 2.0 mini
    Fully reworked board layout
    * 4-layer
    * Raspberry Pi Zero form factor
    * On-board ceramic chip antennas
    [Power.kicad_sch, mmdvm_hs_dual_hat.kicad_pcb, mmdvm_hs_dual_hat.kicad_sch]
